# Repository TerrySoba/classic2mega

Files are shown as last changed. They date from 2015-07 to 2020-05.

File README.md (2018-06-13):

# Classic2mega

This adapter allows the usage of Nintendo Wii Classic Controllers with a Sega Megadrive/Genesis.
Although it is called classic2mega (for megadrive) it also works with other systems that use the same connector like the Commodore Amiga.

It also has a mode to use a Classic Controller as an Amiga mouse.

## Supported input devices
 * Nintendo Classic Controller
 * Nintendo Classic Controller Pro
 * Super Nintendo Mini Controller
 * NES Mini Controller
 
## Adapter Modes
 * Megadrive / Genesis Mode
 * Jump And Run Mode
 * Amiga Mouse Mode
 * Delay Mode

[Building Instructions (german)](doc/building_instructions_de.md)

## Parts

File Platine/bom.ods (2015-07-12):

Classic2Mega BOM
 |  |  |  |  |  | 4
Name | Value | Package | Farnell Number | Unit Price (EUR) | Count
NXP PCA9306D IC |  | SO08 | 2212070 | 0.598 | 1 | 4
Atmel ATMEGA16A |  | TQFP44 | 2425121 | 4.43 | 1 | 4
MICROCHIP MCP1700T-3302E/TT |  | SOT-23 | 1296592 | 0.386 | 1 | 4
MC74HC157ADG |  | SO16 | 9666940 | 0.4 | 1 | 4
VISHAY VLMC310 |  | PLCC-2 | 1659076 | 0.105 | 1 | 4
RALTRON AS-16.000-18 QUARZ |  | HC49/S | 1611761 | 0.249 | 1 | 4
LUMBERG NEB 21 R |  |  | 1217037 | 0.919 | 1 | 4
TSM2310 |  | SOT-23 | 1864585 | 0.121 | 1 | 4
Varistor EZJZ1V120KA |  | “0605” | 1780509 | 0.171 | 1 | 4
Capacitor | 100nF | “0805” | 1759166 | 0.013 | 3 | 12
Capacitor | 22pF | “0805” | 1759195 | 0.021 | 2 | 8
Capacitor | 1µF | “0805” | 2320853 | 0.0294 | 2 | 8
Capacitor | 47µF | “0805” | 2362109 | 0.36 | 1 | 4
Capacitor | 1nF | “0805” | 1907054 | 0.0144 | 1 | 4
STECKER,2REIHEN,5KONT |  |  | 1022235 | 0.271 | 1 | 4
STECKER,1REIHE,2KONT |  |  | 1022245 | 0.09 | 1 | 4
Resistor | 10k | “0805” | 2447553 | 0.0025 | 5 | 20
Resistor | 200k | “0805” | 2057656 | 0.019 | 1 | 4
Resistor | 1M | “0805” | 2447596 | 0.0029 | 1 | 4
Resistor | 1.5k | “0805” | 2447592 | 0.0025 | 1 | 4
Con-subd |  |  | 1653978 | 0.93 | 1 | 4

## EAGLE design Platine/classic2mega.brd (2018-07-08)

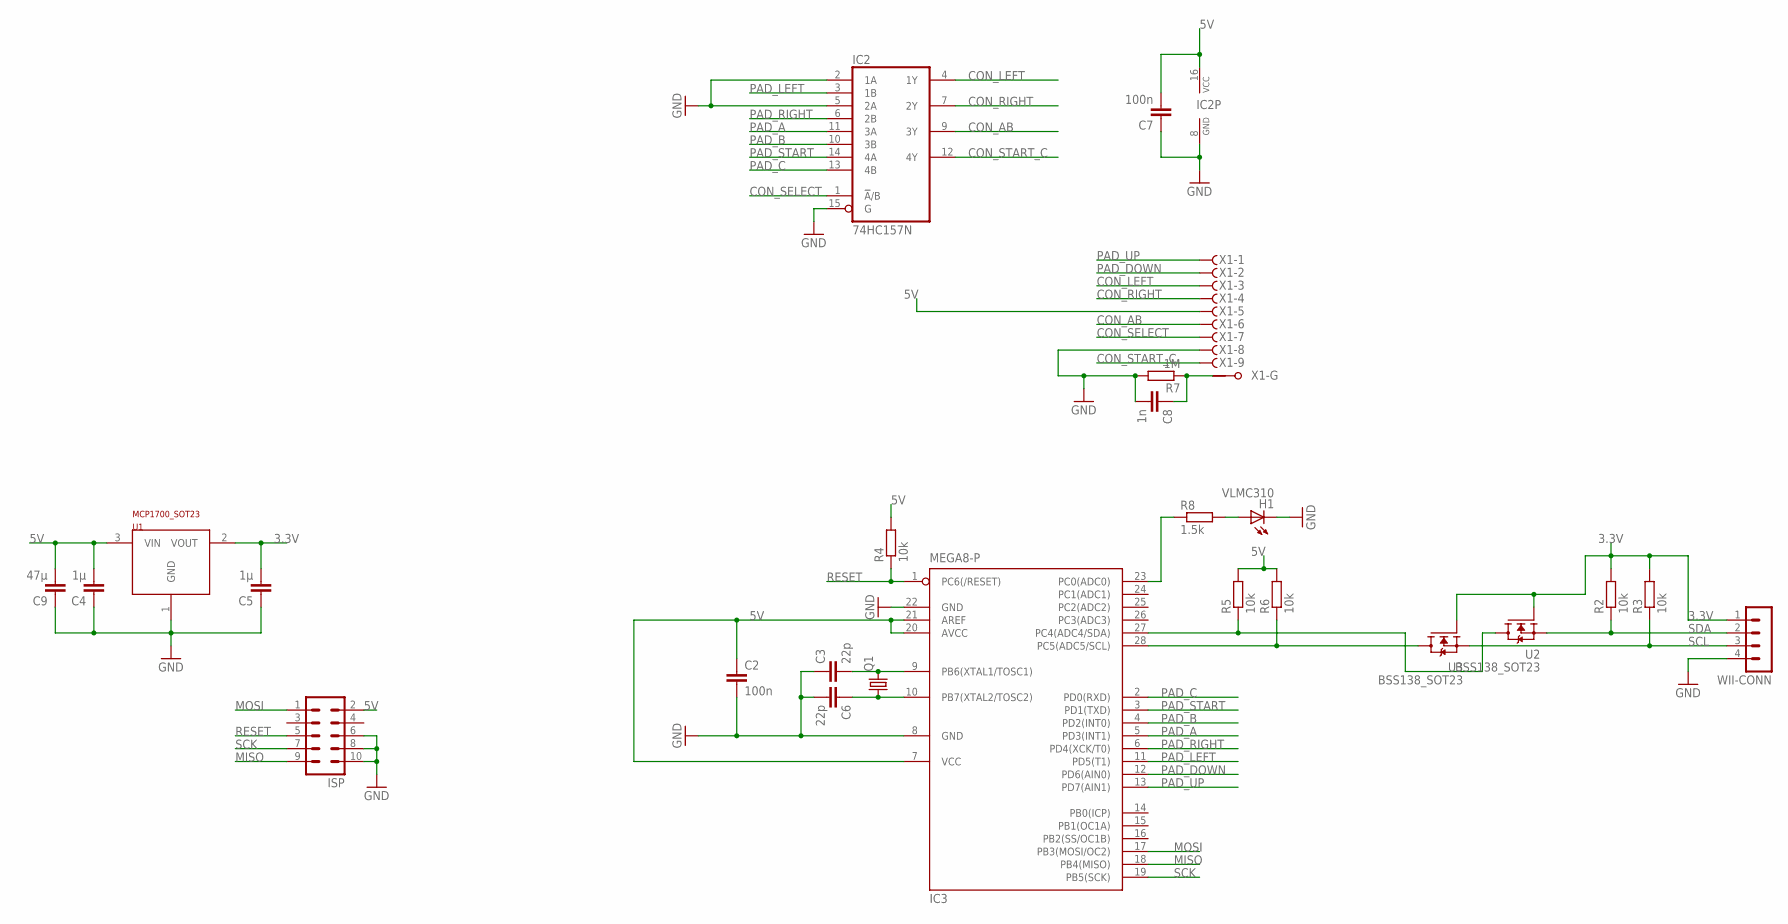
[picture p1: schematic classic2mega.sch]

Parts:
C2, C7: 100n; C0805K
C3, C6: 22p; C0805K
C4, C5: 1µ; C0805K
C8: 1n; C0805K
C9: 47µ; C1210
H1: VLMC310; PLCC-2
IC2: 74HC157N; DIL16
IC3: MEGA8-P; DIL28-3
ISP: MA05-2
Q1: CRYSTALHC49S; HC49/S
R2, R3, R4, R5, R6: 10k; M0805
R7: 1M; M0805
R8: 1.5k; M0805
U1: MCP1700_SOT23; SOT23
U2, U3: BSS138_SOT23; SOT23
WII-CONN: MA04-1
X1: F09HPS; F09HP

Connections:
3.3V: C5.2, R2.2, R3.2, U1.2 (VOUT), U2.1 (G), U3.1 (G), WII-CONN.1
5V: C2.1, C4.2, C7.2, C9.2, IC2.16 (VCC), IC3.7 (VCC), IC3.20 (AVCC), IC3.21 (AREF), ISP.2, R4.2, R5.2, R6.2, U1.3 (VIN), X1.5 (F)
CON_AB: IC2.9 (3Y), X1.6 (F)
CON_LEFT: IC2.4 (1Y), X1.3 (F)
CON_RIGHT: IC2.7 (2Y), X1.4 (F)
CON_SELECT: IC2.1 (!A!/B), X1.7 (F)
CON_START_C: IC2.12 (4Y), X1.9 (F)
GND: C2.2, C3.1, C4.1, C5.1, C6.2, C7.1, C8.2, C9.1, H1.C, IC2.2 (1A), IC2.5 (2A), IC2.8 (GND), IC2.15 (G), IC3.8 (GND), IC3.22 (GND), ISP.6, ISP.8, ISP.10, R7.2, U1.1 (GND), WII-CONN.4, X1.8 (F)
MISO: IC3.18 (PB4(MISO)), ISP.9
MOSI: IC3.17 (PB3(MOSI/OC2)), ISP.1
unnamed: IC3.27 (PC4(ADC4/SDA)), R5.1, U2.3 (D)
unnamed: IC3.23 (PC0(ADC0)), R8.1
unnamed: C3.2, IC3.9 (PB6(XTAL1/TOSC1)), Q1.2
unnamed: IC3.28 (PC5(ADC5/SCL)), R6.1, U3.3 (D)
unnamed: C6.1, IC3.10 (PB7(XTAL2/TOSC2)), Q1.1
unnamed: C8.1, R7.1, X1.G1
unnamed: H1.A, R8.2
PAD_A: IC2.11 (3A), IC3.5 (PD3(INT1))
PAD_B: IC2.10 (3B), IC3.4 (PD2(INT0))
PAD_C: IC2.13 (4B), IC3.2 (PD0(RXD))
PAD_DOWN: IC3.12 (PD6(AIN0)), X1.2 (F)
PAD_LEFT: IC2.3 (1B), IC3.11 (PD5(T1))
PAD_RIGHT: IC2.6 (2B), IC3.6 (PD4(XCK/T0))
PAD_START: IC2.14 (4A), IC3.3 (PD1(TXD))
PAD_UP: IC3.13 (PD7(AIN1)), X1.1 (F)
RESET: IC3.1 (PC6(/RESET)), ISP.5, R4.1
SCK: IC3.19 (PB5(SCK)), ISP.7
SCL: R3.1, U3.2 (S), WII-CONN.3
SDA: R2.1, U2.2 (S), WII-CONN.2

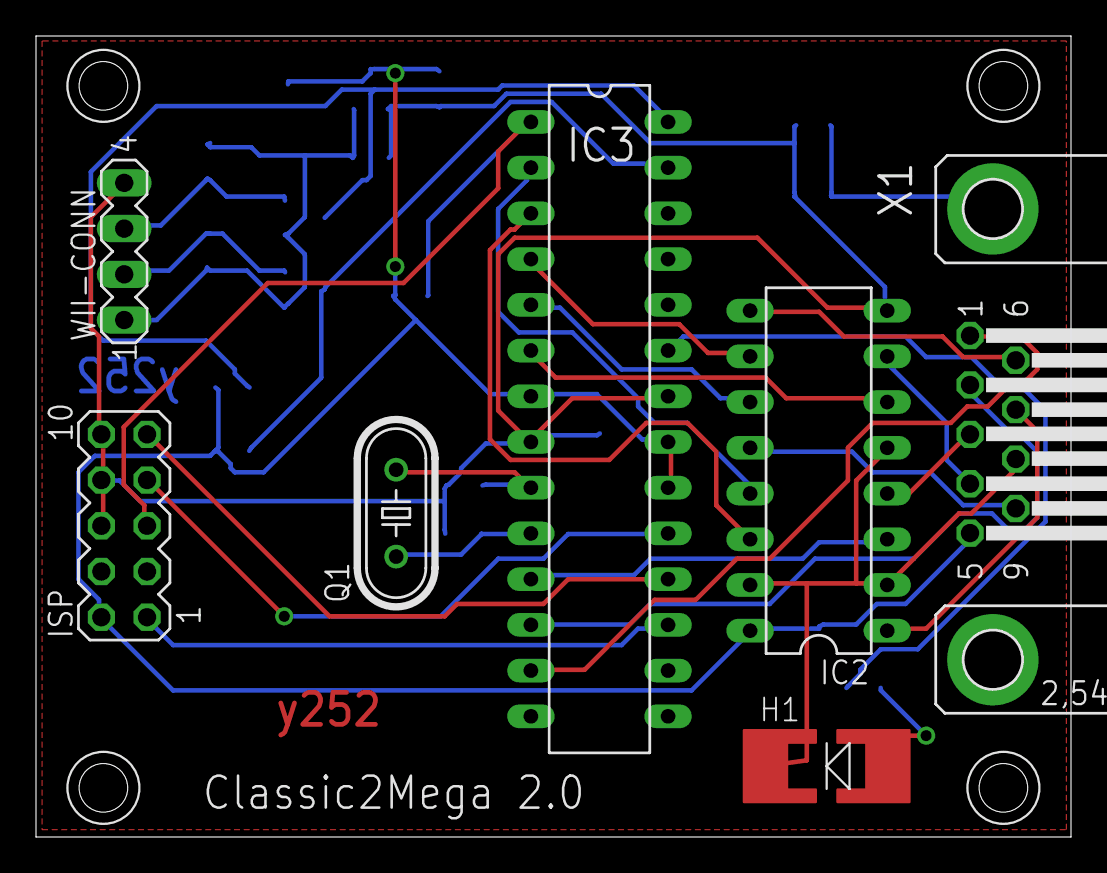
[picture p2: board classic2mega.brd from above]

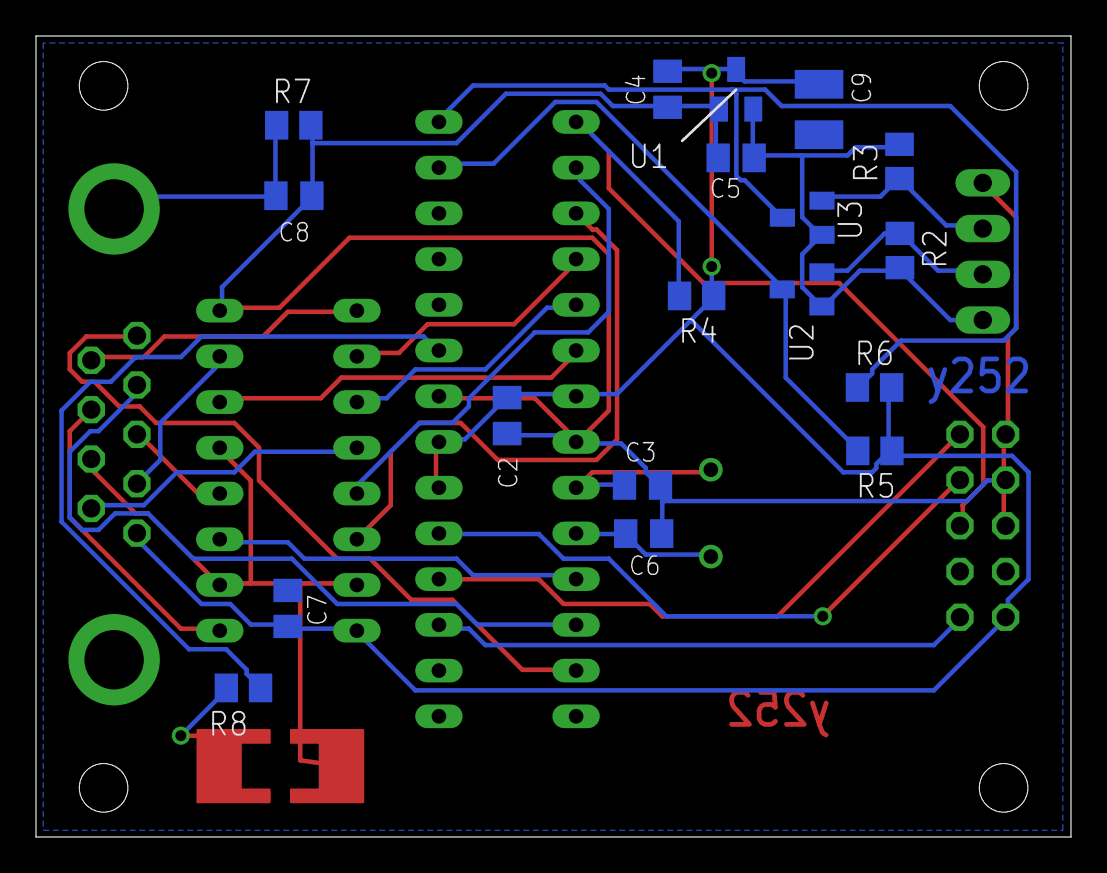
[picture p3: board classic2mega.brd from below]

Board: 2 copper layers, 57.5 x 44.5 mm, 26 parts (18 on the bottom side), 29 nets.

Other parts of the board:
U$6: G028-HOLES

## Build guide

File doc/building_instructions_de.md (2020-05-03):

# Bauanleitung

Dieses Dokument beschreibt wie der Adapter gebaut werden kann.

## Schwierigkeitsgrad

Der Adapter verwendet bedrahtete Bauteile im DIP-Format für die ICs. Diese sind relativ einfach zu löten. Bauteile die weniger als 4 Kontakte aufweisen sind jedoch als SMD ausgeführt. Um diese Bauteile zu platzieren ist auf jeden Fall eine Pinzette erforderlich.

## Benötigte Materialien

Die benötigten Bauelemente sind in folgender Liste aufgeführt:

| Symbol | Name | Value | Package | Reichelt Number | Count |
|---|---|---:|---|---:|---:|
| U2,U3 | BSS 138 SMD | N-Channel MOSFET | SOT-23 | BSS 138 SMD | 2 |
| IC3 |Atmel ATMEGA 8A-PU|	|	DIL-28|	ATMEGA 8A-PU |	1|
| U1 |MICROCHIP MCP1700T-3302E/TT| 3.3V LDO |	SOT-23|	MCP 1700-3302|		1|
| IC2 |MC74HC157ADG|	|	DIL-16| 74HC 157|	1|
| H1 |OSRAM LT L29S-P2R1-25|	|	"0603"|	LT L29S |		1|
| Q2 |RALTRON AS-16.000-18 QUARZ |	|	HC49/S| 16,0000-HC49U-S|		1|
| C1,C6,C7 |Capacitor|	100nF|	“0805”|RND 1500805Y1041|		3|
| C2,C3 |Capacitor|	22pF|	“0805”|	NPO 0805 BG 22P|	2|
| C4,C5 |Capacitor|	1µF|	“0805”|	KEM X7R0805A1,0U|		2|
| C9 |Capacitor|	47µF|	“1210”|	X5R 1210 DC 47U|	1|
| C8 |Capacitor|	1nF|	“0805”|	NPO 0805 BG 1,0N|	1|
| ISP |STECKER,2REIHEN,5KONT| |			|MPE 087-2-010|		1|
| R1,R2,R3,R5,R6 |Resistor|	10k|	“0805”|	RND 0805 1 10K|		5|
| R7 |Resistor|	1M|	“0805”|	RND 0805 1 1,0M|		1|
| R8 |Resistor|	1.5k|	“0805”|	RND 0805 1 1,5K|		1|
| X1 |Con-subd|	|		|D-SUB BU 09EU|		1|

Hier ist eine vorbereiteter Warenkorb bei Reichelt, der alle benötigten Bauteile enthält.

https://www.reichelt.de/my/1487551

Die (unbestückte) Platine kann unter folgendem Link bestellt werden: 
https://aisler.net/p/YHRRFAVE

Darüberhinaus werden folgenden Dinge benötigt:

 * Wii Classic-Controller-Verlängerungskabel (bei eBay ab 5€ zu bekommen)
 * Megadrive Verlängerungskabel (bei eBay ab 5€ zu bekommen)
 * Lötkolben
 * Lötzinn
 * SMD Pinzette
 * Seitenschneider
 * Programmieradapter für Atmel ATMega (ISP-Programmierer) (auf eBay für unter 10€ zu bekommen, z.B. https://www.ebay.de/itm/USBasp-3-3V-5V-ISP-Programmiergerat-USB-Programmer-fur-Atmel-AVR-und-Arduino/252061647559)
 * (Optional, aber empfohlen) Multimeter
 * Kabelbinder (Zur Zugentlastung des Wii-Kabels)
 * Scharfes Messer zur Bearbeitung des Gehäuses
 * Kreuz-Schraubendreher

## PCB Top
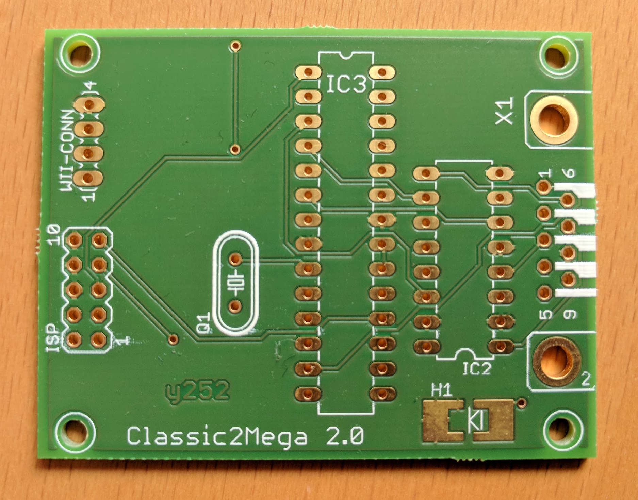
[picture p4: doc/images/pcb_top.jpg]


## PCB Bottom
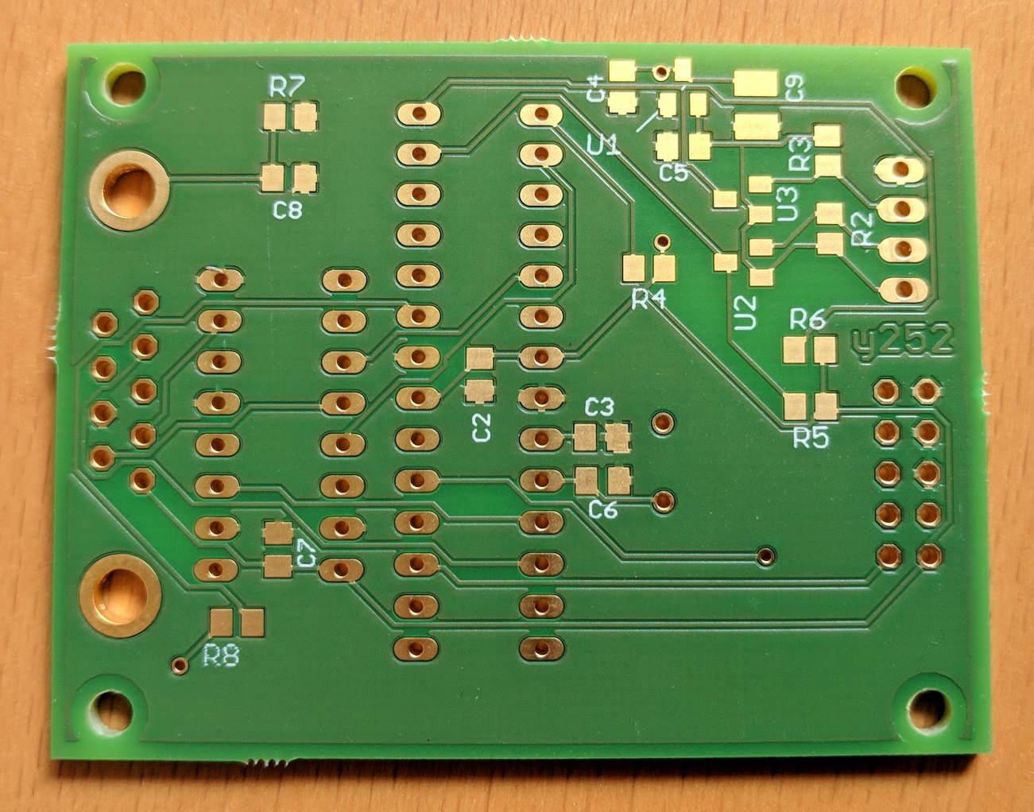
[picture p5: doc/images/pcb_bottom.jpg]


## PCB Top Bestückt
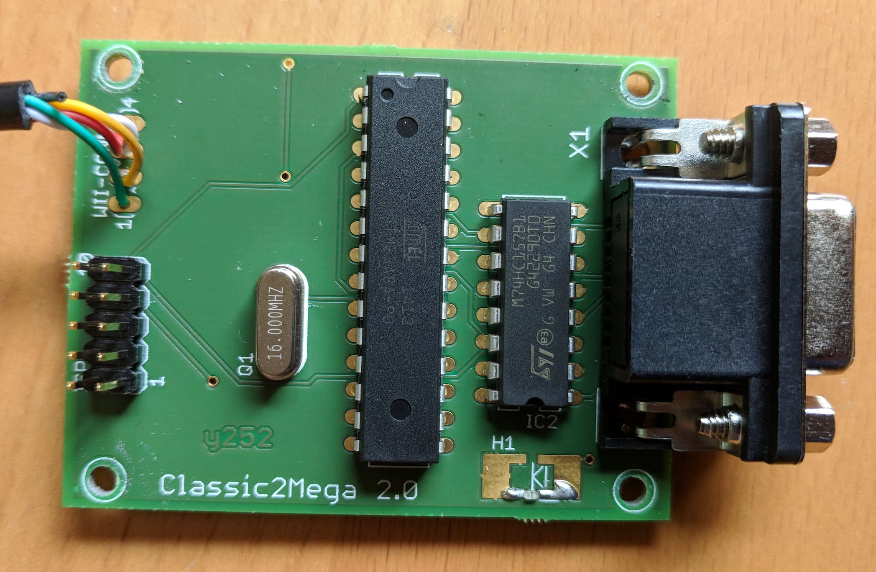
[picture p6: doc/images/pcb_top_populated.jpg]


## PCB Bottom Bestückt
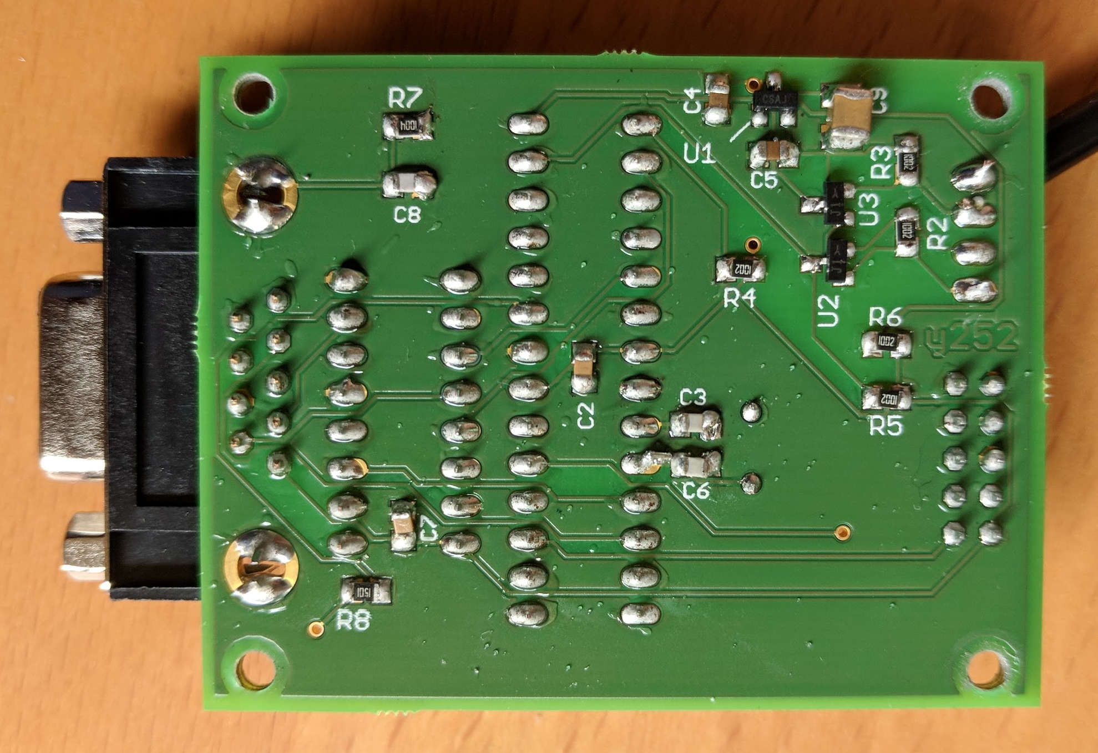
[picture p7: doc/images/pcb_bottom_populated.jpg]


## Firmwareinstallation

Um die Firmware auf dem ATMEGA8 zu installieren ist ein ISP-Programmierer und die zugehörige Software nötig.
Die Firmware kann hier heruntergeladen werden: <a href="firmware.hex">firmware.hex</a>
Außerdem müssen auf dem ATMEGA8 die folgenden Fuses gesetz werden:
HFUSE = 0xD9
LFUSE = 0xE4

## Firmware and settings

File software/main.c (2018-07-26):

/* Name: main.c
 * Project: classic2mega, a Wii Classic Controller to mega drive / genesis adapter
 * Author: Torsten Stremlau <torsten@stremlau.de>
 * Creation Date: 2015-07-11
 * Tabsize: 4
 *
 * License: GNU GPL v2 (see License.txt), GNU GPL v3
 */

#define TW_SCL 100000 // TWI frequency in Hz

#include "twi_speed.h"

#include <avr/io.h>
#include <avr/wdt.h>
#include <avr/interrupt.h>  /* for sei() */
#include <util/delay.h>     /* for _delay_ms() */

#include "bit_tools.h"
#include "twi_func.h"

#include <stdint.h>
#include <stdbool.h>

#define SLAVE_ADDR 0x52     /* address of classic controller and nunchuck */


typedef struct {
    uint8_t   buttons[2];
} report_t;


uint8_t rawData[6];

#define REPORT_BUFFER_COUNT 9

static report_t reportBuffer[REPORT_BUFFER_COUNT];
static int reportBufferPos = 0;

/* I2C initialization */
void myI2CInit(void) {
    twi_init(); // this is a macro from "twi_speed.h"
}

// initialize Wii controller
unsigned char myWiiInit(void) {
    unsigned char buf[2] = {0x40, 0x00};

    return twi_send_data(SLAVE_ADDR, buf, 2);
}


unsigned char fillReportWithWii(void) {
    uint8_t i;
    unsigned char buf[6];

    /* send 0x00 to the controller to tell him we want data! */
    buf[0] = 0x00;
    
    if (!twi_send_data(SLAVE_ADDR, buf, 1)) {
        goto fend;
    }

    _delay_ms(2);
    // _delay_us(100);

    // ------ now get 6 bytes of data
    
    if (!(twi_receive_data(SLAVE_ADDR, buf, 6))) {
        goto fend;
    }

    // for (i = 0; i < 6; i++) {
    for (i = 0; i < 6; i++) {
        rawData[i] = (buf[i] ^ 0x17) + 0x17; // decrypt data
    }

    // split out buttons
#define BTN_rT      GET_BIT(~rawData[4], 1)
#define BTN_start   GET_BIT(~rawData[4], 2)
#define BTN_home    GET_BIT(~rawData[4], 3)
#define BTN_select  GET_BIT(~rawData[4], 4)
#define BTN_lT      GET_BIT(~rawData[4], 5)
#define BTN_down    GET_BIT(~rawData[4], 6)
#define BTN_right   GET_BIT(~rawData[4], 7)
#define BTN_up      GET_BIT(~rawData[5], 0)
#define BTN_left    GET_BIT(~rawData[5], 1)
#define BTN_rZ      GET_BIT(~rawData[5], 2)
#define BTN_x       GET_BIT(~rawData[5], 3)
#define BTN_a       GET_BIT(~rawData[5], 4)
#define BTN_y       GET_BIT(~rawData[5], 5)
#define BTN_b       GET_BIT(~rawData[5], 6)
#define BTN_lZ      GET_BIT(~rawData[5], 7)

    // button mappings (button 0..15)
#define BUTTON_X              0
#define BUTTON_A              1
#define BUTTON_B              2
#define BUTTON_Y              3
#define BUTTON_START          4
#define BUTTON_SELECT         5
#define BUTTON_HOME           6
#define BUTTON_RIGHT_TRIGGER  7
#define BUTTON_LEFT_TRIGGER   8
#define BUTTON_RIGHT_Z        9
#define BUTTON_LEFT_Z        10
#define BUTTON_UP            11
#define BUTTON_DOWN          12
#define BUTTON_LEFT          13
#define BUTTON_RIGHT         14
#define NO_BUTTON            15

#define SET_BUTTON(BUTTON, SOURCE) SET_BIT_VALUE(reportBuffer[reportBufferPos].buttons[BUTTON/8],BUTTON%8,SOURCE)

    reportBufferPos = (reportBufferPos + 1) % REPORT_BUFFER_COUNT;

    SET_BUTTON(BUTTON_X, BTN_x);
    SET_BUTTON(BUTTON_A, BTN_a);
    SET_BUTTON(BUTTON_B, BTN_b);
    SET_BUTTON(BUTTON_Y, BTN_y);
    SET_BUTTON(BUTTON_START, BTN_start);
    SET_BUTTON(BUTTON_SELECT, BTN_select);
    SET_BUTTON(BUTTON_HOME, BTN_home);
    SET_BUTTON(BUTTON_RIGHT_TRIGGER, BTN_rT);
    SET_BUTTON(BUTTON_LEFT_TRIGGER, BTN_lT);
    SET_BUTTON(BUTTON_RIGHT_Z, BTN_rZ);
    SET_BUTTON(BUTTON_LEFT_Z, BTN_lZ);
    SET_BUTTON(BUTTON_UP, BTN_up);
    SET_BUTTON(BUTTON_DOWN, BTN_down);
    SET_BUTTON(BUTTON_LEFT, BTN_left);
    SET_BUTTON(BUTTON_RIGHT, BTN_right);
    SET_BUTTON(NO_BUTTON, 0);


    return 1;

fend:
    // TWCR = (1<<TWINT)|(1<<TWEN)|(1<<TWSTO);
    _delay_us(20);

    /*all_fine:*/
    
    twi_stop();
    return 0;
}


/* This function sets up stuff */
void myInit(void) {

    _delay_ms(300);
    // SET_BIT(PORTC,0);
    myI2CInit();
    _delay_ms(120);
    myWiiInit();
    _delay_ms(1);
    fillReportWithWii();
}


/**
 * This enum maps megadrive buttons to the io pin of PORTD
 * of the ATMEGA8.
 *  e.g. 3 means PD3.
 */
typedef enum {
    MEGADRIVE_A = 3,
    MEGADRIVE_B = 2,
    MEGADRIVE_C = 0,
    MEGADRIVE_START = 1,
    MEGADRIVE_LEFT = 5,
    MEGADRIVE_RIGHT = 4,
    MEGADRIVE_UP = 7,
    MEGADRIVE_DOWN = 6
} megadrive_button;


/**
 * This enum amiga mouse signals to the io pin of PORTD
 * of the ATMEGA8.
 *  e.g. 3 means PD3.
 */
typedef enum {
	MOUSE_V_PULSE = 7,
	MOUSE_VQ_PULSE = 5,
	MOUSE_H_PULSE = 6,
	MOUSE_HQ_PULSE = 4,
	MOUSE_LEFT_BUTTON = 2,
	MOUSE_RIGHT_BUTTON = 0,
} mouse_signals;


/**
 * Sets the megadrive port with given button number (0-7)
 * to pressed state if pressed is true, to non pressed
 * state otherwise.
 * \param button The megadrive button to set
 * \param pressed If true, button will be set to pressed, to unpressed otherwise.
 */
void setMegadriveButton(megadrive_button button, bool pressed)
{
    if (pressed)
    {
        // make pin an output and set to low
        CLR_BIT(PORTD, button);
        SET_BIT(DDRD, button);
    } else {
        // make pin an input (high impedance) and set to high (pull up)
        CLR_BIT(DDRD, button);
        SET_BIT(PORTD, button);
    }
}

#define buttonPressed(button, buffer) ((buffer.buttons[button/8] & (1 << (button%8))) != 0)

/**
 * This function takes the global variable reportBuffer
 * and sets the megadrive port accordingly.
 */
void setMegadrive(bool jumpAndRunMode, bool delayMode)
{
    report_t report;
    if(delayMode)
    {
        report = reportBuffer[(reportBufferPos + 1) % REPORT_BUFFER_COUNT];
    } else {
        report = reportBuffer[reportBufferPos];
    }

    if (jumpAndRunMode)
    {
        setMegadriveButton(MEGADRIVE_A, false);
        setMegadriveButton(MEGADRIVE_B, buttonPressed(BUTTON_X, report) || buttonPressed(BUTTON_Y, report));
        setMegadriveButton(MEGADRIVE_C, false);
        setMegadriveButton(MEGADRIVE_START, false);
        setMegadriveButton(MEGADRIVE_UP, buttonPressed(BUTTON_A, report) || buttonPressed(BUTTON_B, report) || buttonPressed(BUTTON_UP, report));
    }
    else
    {
        setMegadriveButton(MEGADRIVE_A, buttonPressed(BUTTON_Y, report));
        setMegadriveButton(MEGADRIVE_B, buttonPressed(BUTTON_X, report) || buttonPressed(BUTTON_B, report));
        setMegadriveButton(MEGADRIVE_C, buttonPressed(BUTTON_A, report));
        setMegadriveButton(MEGADRIVE_START, buttonPressed(BUTTON_START, report));
        setMegadriveButton(MEGADRIVE_UP, buttonPressed(BUTTON_UP, report));
    }

    setMegadriveButton(MEGADRIVE_LEFT, buttonPressed(BUTTON_LEFT, report));
    setMegadriveButton(MEGADRIVE_RIGHT, buttonPressed(BUTTON_RIGHT, report));
    setMegadriveButton(MEGADRIVE_DOWN, buttonPressed(BUTTON_DOWN, report));
}


static volatile unsigned int mouseStateHorizontal = 0;
static volatile unsigned int mouseStateVertical = 0;

void setAmigaMouse()
{
	report_t report = reportBuffer[reportBufferPos];

	if (buttonPressed(BUTTON_LEFT, report)) --mouseStateHorizontal;
	if (buttonPressed(BUTTON_RIGHT, report)) ++mouseStateHorizontal;
	if (buttonPressed(BUTTON_DOWN, report)) ++mouseStateVertical;
	if (buttonPressed(BUTTON_UP, report)) --mouseStateVertical;

	switch(mouseStateHorizontal % 4)
	{
	case 0:
		setMegadriveButton(MOUSE_H_PULSE, 0);
		setMegadriveButton(MOUSE_HQ_PULSE, 0);
		break;
	case 1:
		setMegadriveButton(MOUSE_H_PULSE, 1);
		setMegadriveButton(MOUSE_HQ_PULSE, 0);
		break;
	case 2:
		setMegadriveButton(MOUSE_H_PULSE, 1);
		setMegadriveButton(MOUSE_HQ_PULSE, 1);
		break;
	case 3:
		setMegadriveButton(MOUSE_H_PULSE, 0);
		setMegadriveButton(MOUSE_HQ_PULSE, 1);
		break;
	}

	switch(mouseStateVertical % 4)
	{
	case 0:
		setMegadriveButton(MOUSE_V_PULSE, 0);
		setMegadriveButton(MOUSE_VQ_PULSE, 0);
		break;
	case 1:
		setMegadriveButton(MOUSE_V_PULSE, 1);
		setMegadriveButton(MOUSE_VQ_PULSE, 0);
		break;
	case 2:
		setMegadriveButton(MOUSE_V_PULSE, 1);
		setMegadriveButton(MOUSE_VQ_PULSE, 1);
		break;
	case 3:
		setMegadriveButton(MOUSE_V_PULSE, 0);
		setMegadriveButton(MOUSE_VQ_PULSE, 1);
		break;
	}


	setMegadriveButton(MOUSE_LEFT_BUTTON, buttonPressed(BUTTON_A, report));
	setMegadriveButton(MOUSE_RIGHT_BUTTON, buttonPressed(BUTTON_B, report));
}

/**
 *  This function sets the outputs used by the megadrive plug to
 *  high impedance and pull down.
 */
void setupMegadrive()
{
    // all inputs == high impedance
    DDRD = 0x00;

    // all low == pulldown
    PORTD = 0x00;
}



/* ------------------------------------------------------------------------- */

typedef enum _Mode
{
	UNINITIALIZED = 0,
	MEGADRIVE_MODE = 1,
	JUMP_RUN_MODE = 2,
	AMIGA_MOUSE_MODE = 3,
	DELAY_MODE = 4
} AdapterMode;

int main(void)
{
	AdapterMode adapterMode = MEGADRIVE_MODE;
	AdapterMode lastAdapterMode = UNINITIALIZED;

start:
    cli();
    wdt_disable();
    /* Even if you don't use the watchdog, turn it off here. On newer devices,
     * the status of the watchdog (on/off, period) is PRESERVED OVER RESET!
     */

    // initialize reportBuffer with 0
    for (int i = 0; i < REPORT_BUFFER_COUNT; ++i)
    {
        reportBuffer[i].buttons[0] = 0;
        reportBuffer[i].buttons[1] = 0;
    }

    // make PORTC_0 (LED) an output pin
    SET_BIT(DDRC, 0);

    for (int i = 0; i < 5; ++i)
    {
	SET_BIT(PORTC, 0);
	_delay_ms(50);
	CLR_BIT(PORTC, 0);
	_delay_ms(50);
	
    }


    sei();

    myInit();
    setupMegadrive();

    for(;;){                /* main event loop */
        wdt_reset();

        // check if mode has changed, if it did change then reset ports
        if (adapterMode != lastAdapterMode)
        {
        	for (int i = 0; i < 8; ++i)
            {
            	setMegadriveButton(i, 0);
            }
        }
        lastAdapterMode = adapterMode;

        fillReportWithWii();
        
        if (adapterMode == AMIGA_MOUSE_MODE) {
        	setAmigaMouse();
        } else {
        	setMegadrive(adapterMode == JUMP_RUN_MODE, adapterMode == DELAY_MODE);
        }

        report_t report = reportBuffer[reportBufferPos];

        if (buttonPressed(BUTTON_B, report) && buttonPressed(BUTTON_SELECT, report) && buttonPressed(BUTTON_UP, report))
        {
        	adapterMode = JUMP_RUN_MODE;
        	CLR_BIT(PORTC, 0);
        }

        if (buttonPressed(BUTTON_B, report) && buttonPressed(BUTTON_SELECT, report) && buttonPressed(BUTTON_DOWN, report))
        {
        	adapterMode = MEGADRIVE_MODE;
        	CLR_BIT(PORTC, 0);
        }

        if (buttonPressed(BUTTON_B, report) && buttonPressed(BUTTON_SELECT, report) && buttonPressed(BUTTON_LEFT, report))
        {
        	adapterMode = AMIGA_MOUSE_MODE;
            CLR_BIT(PORTC, 0);
        }

        if (buttonPressed(BUTTON_A, report) && buttonPressed(BUTTON_START, report) && buttonPressed(BUTTON_RIGHT, report))
        {
            adapterMode = DELAY_MODE;
            SET_BIT(PORTC, 0);
        }


        /* If the gamepad starts feeding us 0xff, we have to restart to recover */
        if ((rawData[0] == 0xff) && (rawData[1] == 0xff) && (rawData[2] == 0xff) && (rawData[3] == 0xff) && (rawData[4] == 0xff) && (rawData[5] == 0xff)) {
            goto start;
        }
    }
    return 0;
}

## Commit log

2015-06-27 Initial import
    [bom.ods, classic2mega.brd, classic2mega.sch]
2015-06-27 Add "y252" string to backside copper
    [classic2mega.brd]
2015-06-27 Version used for first pcb-production
    [classic2mega.brd]
2015-07-12 press x to light led
    [bom.ods]
2018-06-03 Fix button mapping in jumn and run mode
    [main.c]
2018-06-05 Add BOM
2018-06-05 Fix BOM
2018-06-10 Add symbols to BOM
2018-06-10 New board revison
    [classic2mega.brd, classic2mega.sch]
2018-06-15 Add images of PCB
2018-07-08 Replace i2c level shifter with discrete components
    [classic2mega.brd, classic2mega.sch]
2018-07-08 Change ICs to DIP packages
    [classic2mega.brd, classic2mega.sch]
2018-07-08 Change C9 to 1210 footprint
    [classic2mega.brd, classic2mega.sch]
2018-07-08 Remove signal lines under crystal
    [classic2mega.brd]
2018-07-08 Move 100nf closer to 5v of ic
    [classic2mega.brd]
2018-07-19 Change to atmega8 and 8MHz internal oscillator
    [main.c]
2018-07-21 Update BOM
2018-07-26 Blink LED at startup
2018-07-26 Add PCB link
2018-07-26 Add photos of PCB
